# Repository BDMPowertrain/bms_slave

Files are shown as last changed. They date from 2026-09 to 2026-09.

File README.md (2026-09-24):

<p align="center" width="100%">
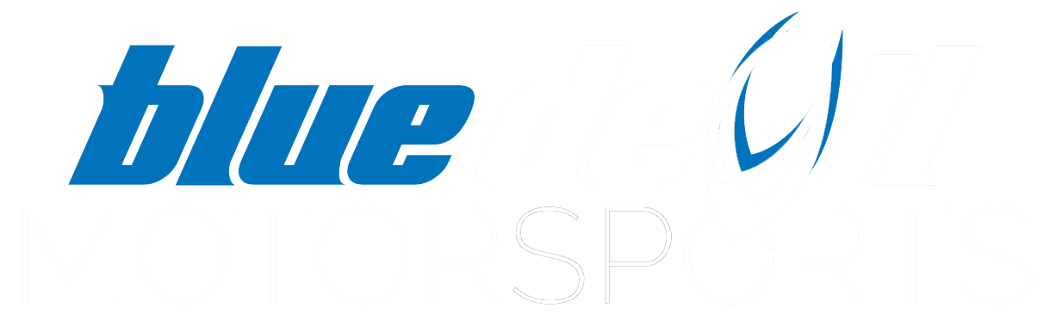
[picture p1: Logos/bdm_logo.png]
  
</p>

<h1 align="center">BOARD_NAME</h1>
<p align="center">Board Name</p>
<p align="center"><em>One-line description of what this board does.</em></p>

<p align="center" width="100%">
  <a href="https://github.com/BDMPowertrain/PLACEHOLDER/actions/workflows/ci.yaml">
    
  </a>
</p>

<p align="center" width="100%">
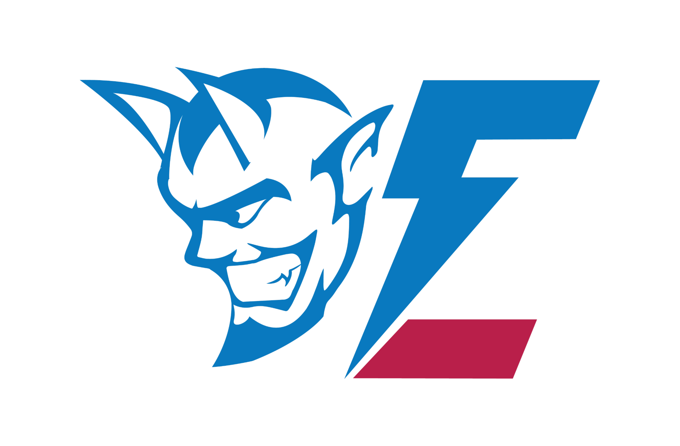
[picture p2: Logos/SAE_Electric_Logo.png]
    
</p>

***

<p align="center">
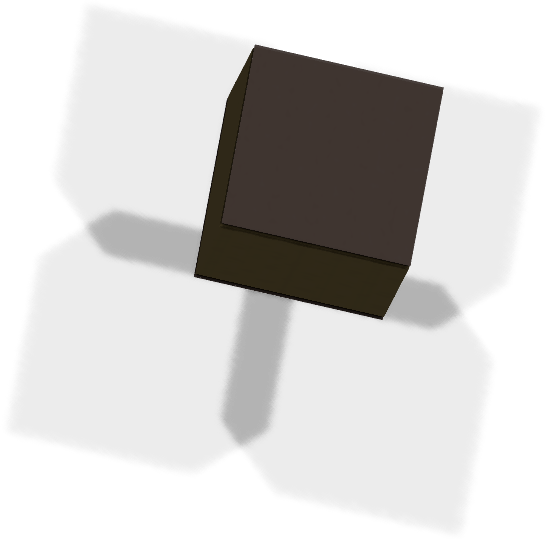
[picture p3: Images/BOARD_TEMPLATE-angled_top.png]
3D Top Angled
  
&nbsp; &nbsp; &nbsp; &nbsp;
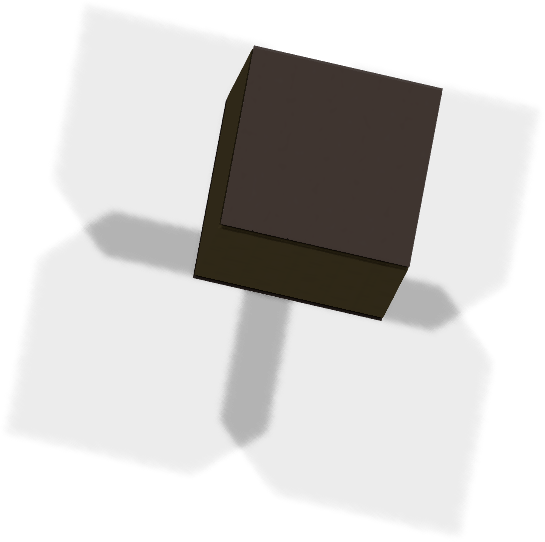
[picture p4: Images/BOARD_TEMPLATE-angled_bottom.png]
3D Bottom Angled
  
</p>

***

## SPECIFICATIONS

| Parameter | Value |
| --- | --- |
| Dimensions | 0.0 × 0.0 mm |
| Company | Blue Devil Motor Sports |
| Designer | Author |
| Revision | + (Unreleased) |

***

## WORKING ON THIS BOARD

> This file is regenerated automatically on every CI run — don't edit it by
> hand. For the full contributor guide (setup, daily commands, commit
> conventions, PR etiquette, and what to do when something goes wrong), see
> the [board_template README](https://github.com/BDMPowertrain/board_template#readme).

**Change the variant** as the board moves through Design → Procurement →
Fabrication:

    ./configure.sh --variant

**Change board metadata** (title, description, designer, company):

    ./configure.sh

RELEASED is never set by hand — push a version tag and CI produces it
automatically:

    git tag 1.0.0
    git push origin 1.0.0

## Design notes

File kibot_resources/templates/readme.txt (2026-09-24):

<p align="center" width="100%">
  
</p>

<h1 align="center">${BOARD_NAME}</h1>
<p align="center">${PROJECT_NAME}</p>
<p align="center"><em>${DESCRIPTION}</em></p>

<p align="center" width="100%">
  <a href="${GIT_URL}/actions/workflows/ci.yaml">
    CI Badge
  </a>
</p>

<p align="center" width="100%">
    
</p>

***

<p align="center">
  3D Top Angled
&nbsp; &nbsp; &nbsp; &nbsp;
  3D Bottom Angled
</p>

***

## SPECIFICATIONS

| Parameter | Value |
| --- | --- |
| Dimensions | ${bb_w_mm} × ${bb_h_mm} mm |
| Company | ${COMPANY} |
| Designer | ${DESIGNER} |
| Revision | ${REVISION} |

***

## WORKING ON THIS BOARD

> This file is regenerated automatically on every CI run — don't edit it by
> hand. For the full contributor guide (setup, daily commands, commit
> conventions, PR etiquette, and what to do when something goes wrong), see
> the [board_template README](https://github.com/BDMPowertrain/board_template#readme).

**Change the variant** as the board moves through Design → Procurement →
Fabrication:

    ./configure.sh --variant

**Change board metadata** (title, description, designer, company):

    ./configure.sh

RELEASED is never set by hand — push a version tag and CI produces it
automatically:

    git tag 1.0.0
    git push origin 1.0.0

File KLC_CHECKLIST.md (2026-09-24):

# KLC Compliance Checklist

Use this when creating or reviewing a symbol or footprint for Prism's
catalog (see the main [README](README.md#7-creating-symbols-footprints-and-adding-images),
section 7). Prism checks every submission against KLC (the KiCad Library
Convention) automatically, using `kicad-library-utils`'s checking scripts.
Go through the relevant checklist below before you submit, so nothing gets
caught by that automated check that you could have caught yourself first.

> **A note on precision.** Both official homes of `kicad-library-utils`
> ([github.com/KiCad/kicad-library-utils](https://github.com/KiCad/kicad-library-utils)
> and [gitlab.com/kicad/libraries/kicad-library-utils](https://gitlab.com/kicad/libraries/kicad-library-utils))
> are archived, with 27 branches for different KiCad versions and no single
> current canonical one. Which exact version Prism actually runs server-side
> isn't documented anywhere accessible from this repo. What follows is the
> stable, well-established core of KLC, the part that's been consistent
> across essentially every version of the tool since KiCad 6, not a claim
> that this list is the complete, exact rule set Prism enforces. If Prism's
> check flags something not listed here, that's a real finding: fix it, and
> consider asking a lead to add it to this file.

## Required symbol fields (properties)

Every symbol needs these set correctly before submission. In KiCad's Symbol
Editor, these are the Fields shown in the symbol's Properties dialog
(right-click the symbol → **Symbol Properties**, or the Fields table in the
Symbol Editor itself):

| Field | Required content | Visible on schematic? |
|---|---|---|
| `Reference` | Correct prefix for the part type, e.g. `R?`, `U?` (see the prefix table below); the `?` is what KiCad replaces with a number when the symbol is placed | Yes |
| `Value` | The MPN for ICs and complex parts, or the actual value (`10k`, `100nF`, `32.768kHz`) for simple passives | Yes |
| `Footprint` | Either left blank (only if the part is genuinely footprint-agnostic) or an exact `Library:FootprintName` reference | No, hidden |
| `Datasheet` | A direct link to the manufacturer's PDF, never a product page or distributor listing | No, hidden |
| `Description` (KiCad's internal `ki_description`) | A real, searchable one-line description of what the part actually *is* and *does*, not the MPN repeated back | No, hidden |
| `ki_keywords` | Space-separated search terms (function, package type, common synonyms) so the part is findable by more than its exact MPN | No, hidden |
| `ki_fp_filters` | Footprint name patterns, e.g. `SOIC*` or `SOT-23*`, so KiCad's footprint-assignment tool only suggests sensible candidates for this part | No, hidden |

**Why `Footprint` and `Datasheet` are hidden but `Reference` and `Value`
aren't:** the two visible fields are what a reviewer actually needs to read
off the printed schematic to identify the part. The rest is metadata for
tooling (BOM generation, footprint assignment, the library browser's
search), and clutters the schematic if shown.

## Reference designator prefixes

| Component | Prefix |
|---|---|
| Resistors | `R` |
| Capacitors | `C` |
| Inductors | `L` |
| Diodes | `D` |
| Transistors / FETs | `Q` |
| ICs (logic, analog, MCU, power, driver, interface) | `U` |
| Crystals / oscillators | `Y` |
| Connectors | `J` |
| Switches / buttons | `SW` |
| Test points | `TP` |
| Ferrite beads | `FB` |

## Symbol checklist

- [ ] Symbol name is the exact MPN, or a clear standard generic name if
      there isn't one part number that applies.
- [ ] `Reference` field prefix matches the part type (table above) and
      defaults to a bare prefix with no number, e.g. `U?` not `U1`.
- [ ] `Value` field is set correctly per the table above.
- [ ] `Footprint` field is either blank (deliberately) or points at the
      exact intended footprint in `Library:FootprintName` format.
- [ ] `Datasheet` field is a direct PDF link, not a product page.
- [ ] `Description` (`ki_description`) is filled in with a real, useful
      one-line description, not left blank or just repeating the MPN.
- [ ] `ki_keywords` has enough search terms that someone looking for this
      part by function, not just exact MPN, can actually find it.
- [ ] `ki_fp_filters` lists sensible footprint name patterns for this part.
- [ ] Every pin is numbered to exactly match the datasheet, no gaps, no
      duplicates.
- [ ] Every pin has the correct electrical type set (input, output,
      bidirectional, power input, passive, open collector, no-connect,
      etc.), not left on whatever the default was.
- [ ] Power and ground pins that must always be connected are marked
      **Power Input**, not left as generic passive or input pins.
- [ ] Unused pins are explicitly marked no-connect (small X), not just
      left floating with nothing indicating that's intentional.
- [ ] Pins sit on the 100mil (2.54mm) grid, with a consistent pin length
      across the whole symbol.
- [ ] Body outline uses a consistent, standard line width; no stray or
      overlapping graphic elements left over from editing.
- [ ] Reference and value text don't overlap the symbol body or each
      other, and are a consistent, readable size.
- [ ] No duplicate or overlapping pins at the same location.
- [ ] For multi-unit parts (e.g. a quad op-amp), each unit is split out
      and numbered correctly, with a shared unit for common power/ground
      pins if the part has one.
- [ ] Pin numbers checked against the datasheet's pin table one more time,
      right before submitting.

## Footprint checklist

- [ ] Footprint name follows a clear, consistent convention:
      `SOIC-16_3.9x9.9mm_P1.27mm`-style for standard packages,
      `MPN_Package` for custom ones. Nothing ambiguous or generic.
- [ ] Every pad is numbered to exactly match the schematic symbol's pin
      numbers; this is what makes the netlist resolve correctly.
- [ ] Pad shapes and sizes match the datasheet's mechanical/land-pattern
      drawing, not just eyeballed from a similar part.
- [ ] Pin 1 (or the equivalent orientation marker, a dot, notch, or
      bevel) is clearly marked on the silkscreen layer.
- [ ] A courtyard outline exists on `F.CrtYd` (or `B.CrtYd` for a
      bottom-side part), with a small clearance margin around the part's
      true physical body, not just the pads.
- [ ] Silkscreen graphics don't overlap any pad or exposed copper.
- [ ] The `F.Fab` (or `B.Fab`) layer shows an accurate outline of the
      part's physical body, for assembly reference.
- [ ] Reference designator text is placed somewhere it won't end up
      hidden under the part once assembled, and is a readable size.
- [ ] Value/reference text doesn't overlap pads, the courtyard boundary,
      or where neighboring components are expected to sit.
- [ ] Soldermask and paste clearance/expansion is set sensibly for the
      pad type, not left at some accidental default that bridges pads.
- [ ] For through-hole parts: drill sizes match the datasheet, with the
      correct plated vs. non-plated designation.
- [ ] A 3D model is attached and correctly aligned, scaled, and rotated
      to match the real part, if one is available.
- [ ] Footprint checked against the physical part with calipers (pad
      pitch, body size) before committing, especially for anything drawn
      by hand from a datasheet rather than downloaded from a vendor.

## Full official rule set

[klc.kicad.org](https://klc.kicad.org) and the
[kicad-library-utils](https://github.com/kicad/kicad-library-utils)
repository (the `klc-check/` scripts there are the basis for what Prism
runs against your submission). This file covers what people actually get
wrong most often, not the complete spec.

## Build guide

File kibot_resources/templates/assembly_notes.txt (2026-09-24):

ASSEMBLY NOTES (UNLESS OTHERWISE SPECIFIED)

1)	DO NOT POPULATE PARTS ARE MARKED WITH A RED CROSS.

2)	DO NOT POPULATE PARTS ARE NOT PRESENT IN THE BOM.

3)	IF CONFLICTING INFORMATION IS FOUND BETWEEN THE ASSEMBLY
	FILE AND BOM, BOM SHOULD BE USED AS THE MAIN SOURCE.

4)	CONFORMAL COATING IS NOT REQUIRED.

5)	DOT IDENTIFIES PIN #1 LOCATION AND DEVICE ORIENTATION
	WHEN VIEWED FROM THE TOP.

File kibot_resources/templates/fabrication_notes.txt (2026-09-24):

FABRICATION NOTES (UNLESS OTHERWISE SPECIFIED)

1)	FABRICATE PER IPC-6012A CLASS 2.

2)	OUTLINE DEFINED IN SEPARATE GERBER FILE WITH
	"Edge_Cuts.GBR" SUFFIX.

	DIMENSIONS OF CIRCUMSIZED RECTANGLE SHOWN ON THIS
	DRAWING FOR REFERENCE ONLY.

3)	SEE SEPARATE DRILL FILES WITH ".DRL" SUFFIX 
	FOR HOLE LOCATIONS.

	SELECTED HOLE LOCATIONS SHOWN ON THIS DRAWING 
	FOR REFERENCE ONLY.

4)	SURFACE FINISH: ${pcb_finish_cap}

5)	SOLDERMASK ON BOTH SIDES OF THE BOARD SHALL 
	BE LPI, COLOR ${solder_mask_color_text_cap}.

6)	SILK SCREEN LEGEND TO BE APPLIED PER LAYER 
	STACKUP USING ${silk_screen_color_text_cap} NON-CONDUCTIVE EPOXY INK.

7)	ALL VIAS ARE TENTED ON BOTH SIDES UNLESS 
	SOLDERMASK OPENED IN GERBER.

8)	VENDOR SHOULD FOLLOW ROHS COMPLIANT PROCESS 
	AND Pb FREE FOR MANUFACTURING

9)	PCB MATERIAL REQUIREMENTS:

	A.	FLAMMABILITY RATING MUST MEET OR EXCEED 
		UL94V-0 REQUIREMENTS.
	B.	Tg 170 C OR EQUIVALENT.
	C.	EQUIVALENT MATERIAL SHALL BE RoHS COMPLIANT, 
		HALOGEN FREE AND APPROVED BY ${COMPANY_cap}.

10)	DESIGN GEOMETRY MINIMUM FEATURE SIZES:

	BOARD SIZE				${bb_w_mm} × ${bb_h_mm} mm
	BOARD THICKNESS		${thickness_mm} mm
	TRACE WIDTH			${track_mm} mm
	TRACE TO TRACE		${clearance_mm} mm
	MIN. HOLE (PTH)			${drill_pth_real_mm} mm
	MIN. HOLE (NPTH)		${drill_npth_real_mm} mm
	ANNULAR RING			${oar_mm} mm
	COPPER TO HOLE		${c2h_mm} mm
	COPPER TO EDGE		${c2e_mm} mm
	HOLE TO HOLE			${h2h_mm} mm
#?stackup and impedance_controlled

#?stackup and impedance_controlled
11)	REFER TO IMPEDANCE TABLE FOR IMPEDANCE CONTROL REQUIREMENTS.
#?stackup and impedance_controlled

#?stackup and impedance_controlled
12)	CONFIRM SPACE WIDTHS AND SPACINGS.

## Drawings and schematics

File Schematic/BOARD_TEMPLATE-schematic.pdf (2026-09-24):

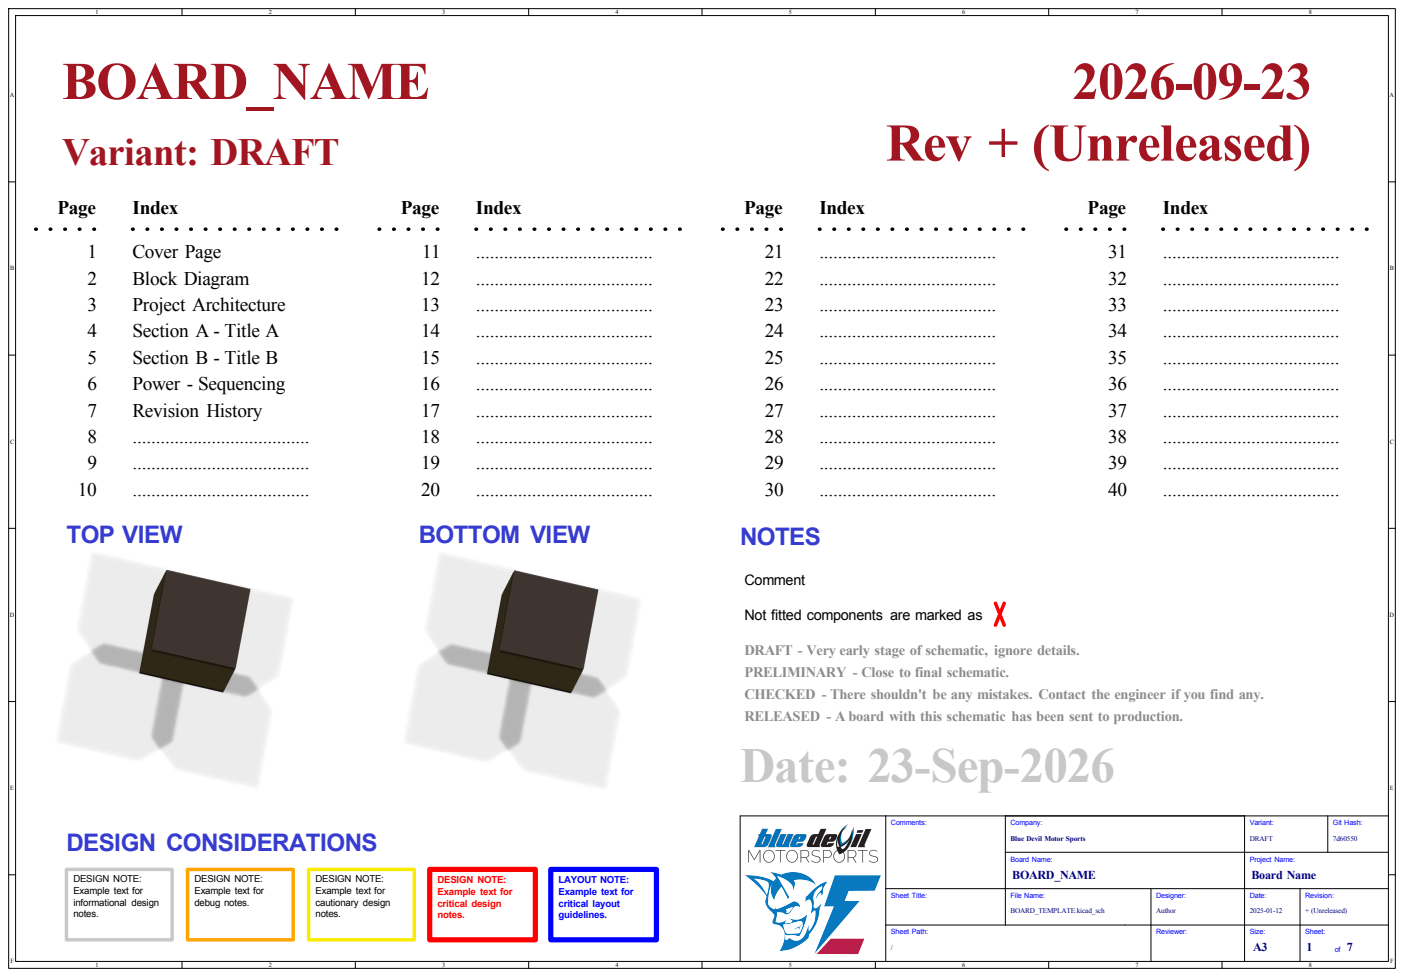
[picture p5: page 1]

...................................... Date: 23-Sep-2026
CHECKED - There shouldn't be any mistakes. Contact the engineer if you find any. ......................................

Not fitted components are marked as

DRAFT - Very early stage of schematic, ignore details.
PRELIMINARY - Close to final schematic.

RELEASED - A board with this schematic has been sent to production.

Revision: + (Unreleased) Date: Project Name: 2025-01-12 Reviewer: Designer:

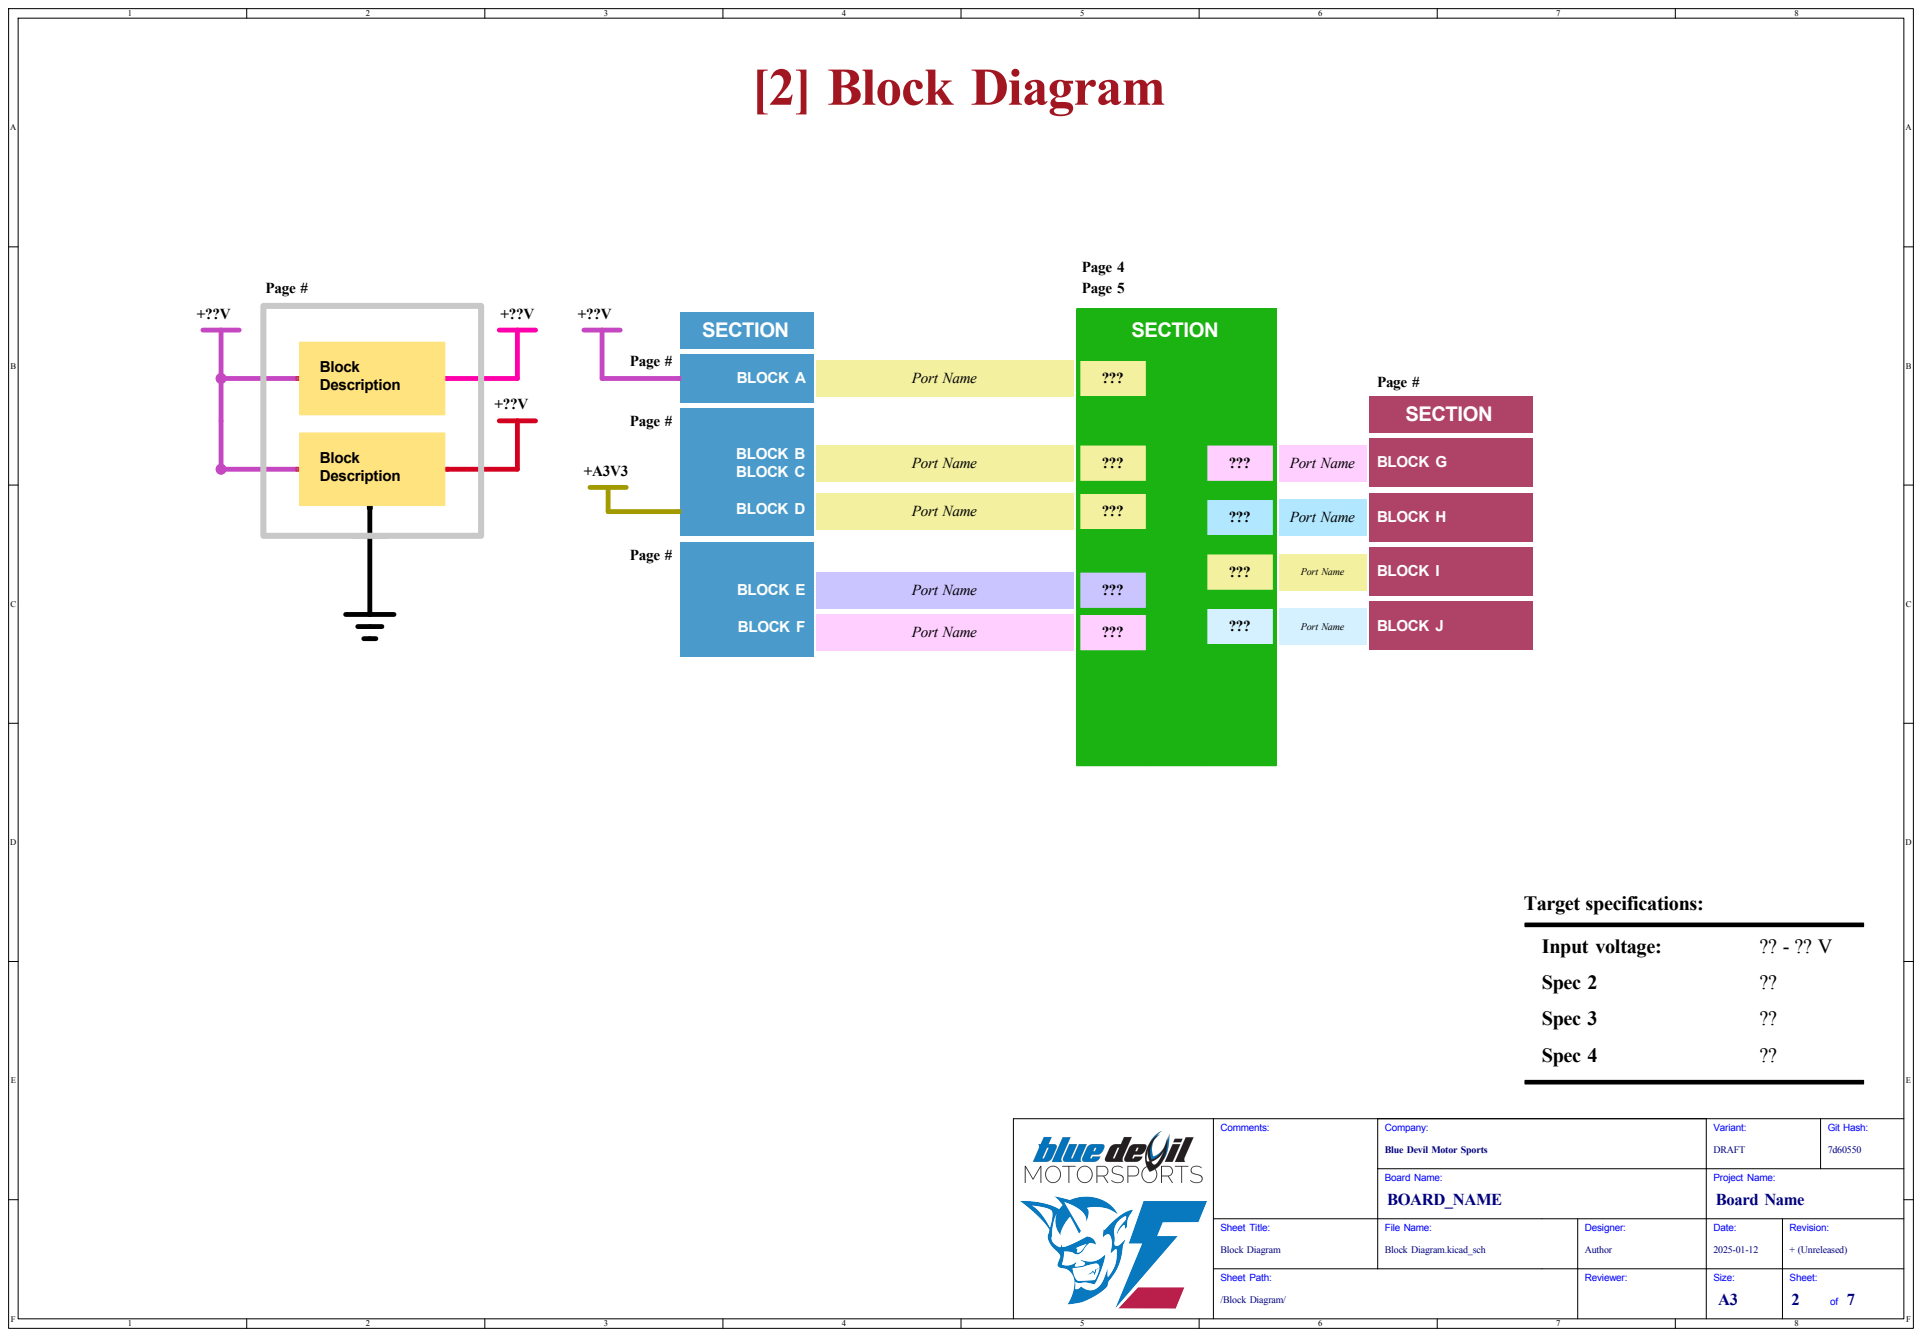
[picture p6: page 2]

Port Name

/Block Diagram/ Sheet Path: Block Diagram

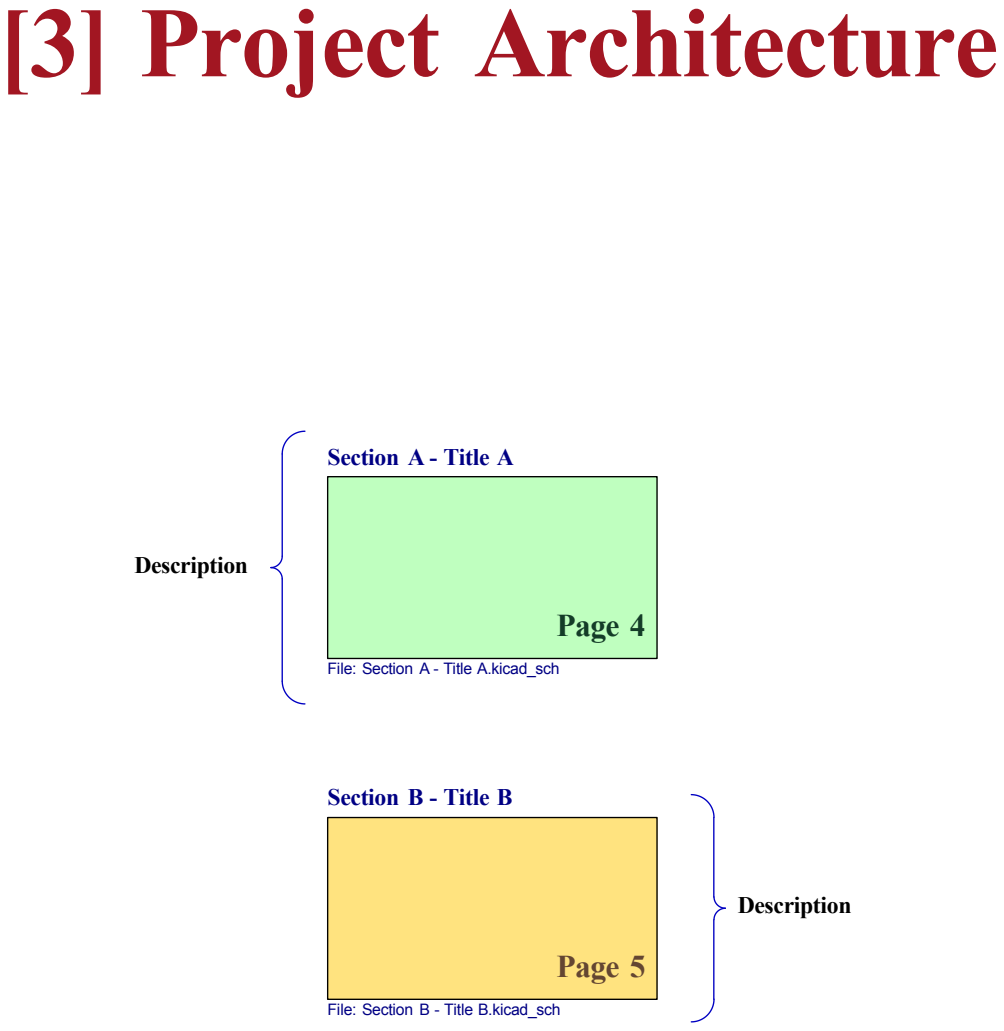
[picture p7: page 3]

Revision: + (Unreleased) Date: Project Name: 2025-01-12 Reviewer: Designer:

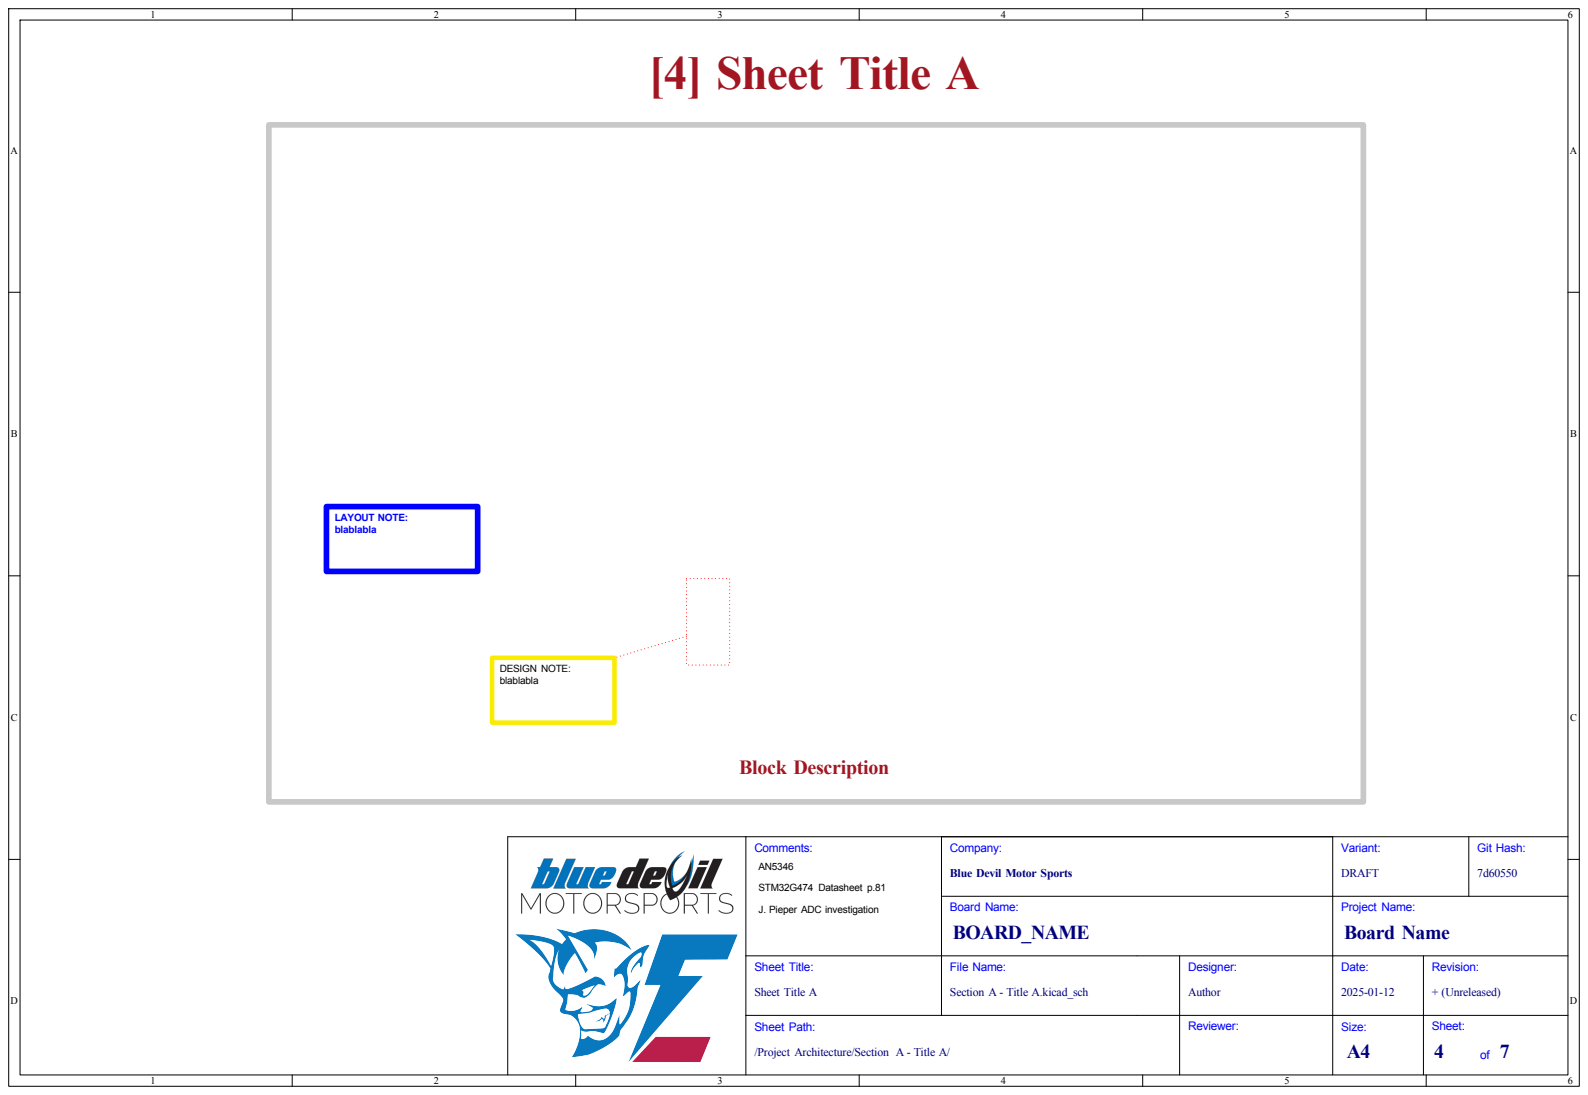
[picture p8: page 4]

J. Pieper ADC investigation (https://jpieper.com/2023/07/24/stm32g4-adc-performance-part-2/) STM32G474 Datasheet p.81 AN5346

/Project Architecture/Section A - Title A/ Sheet Path: Sheet Title A

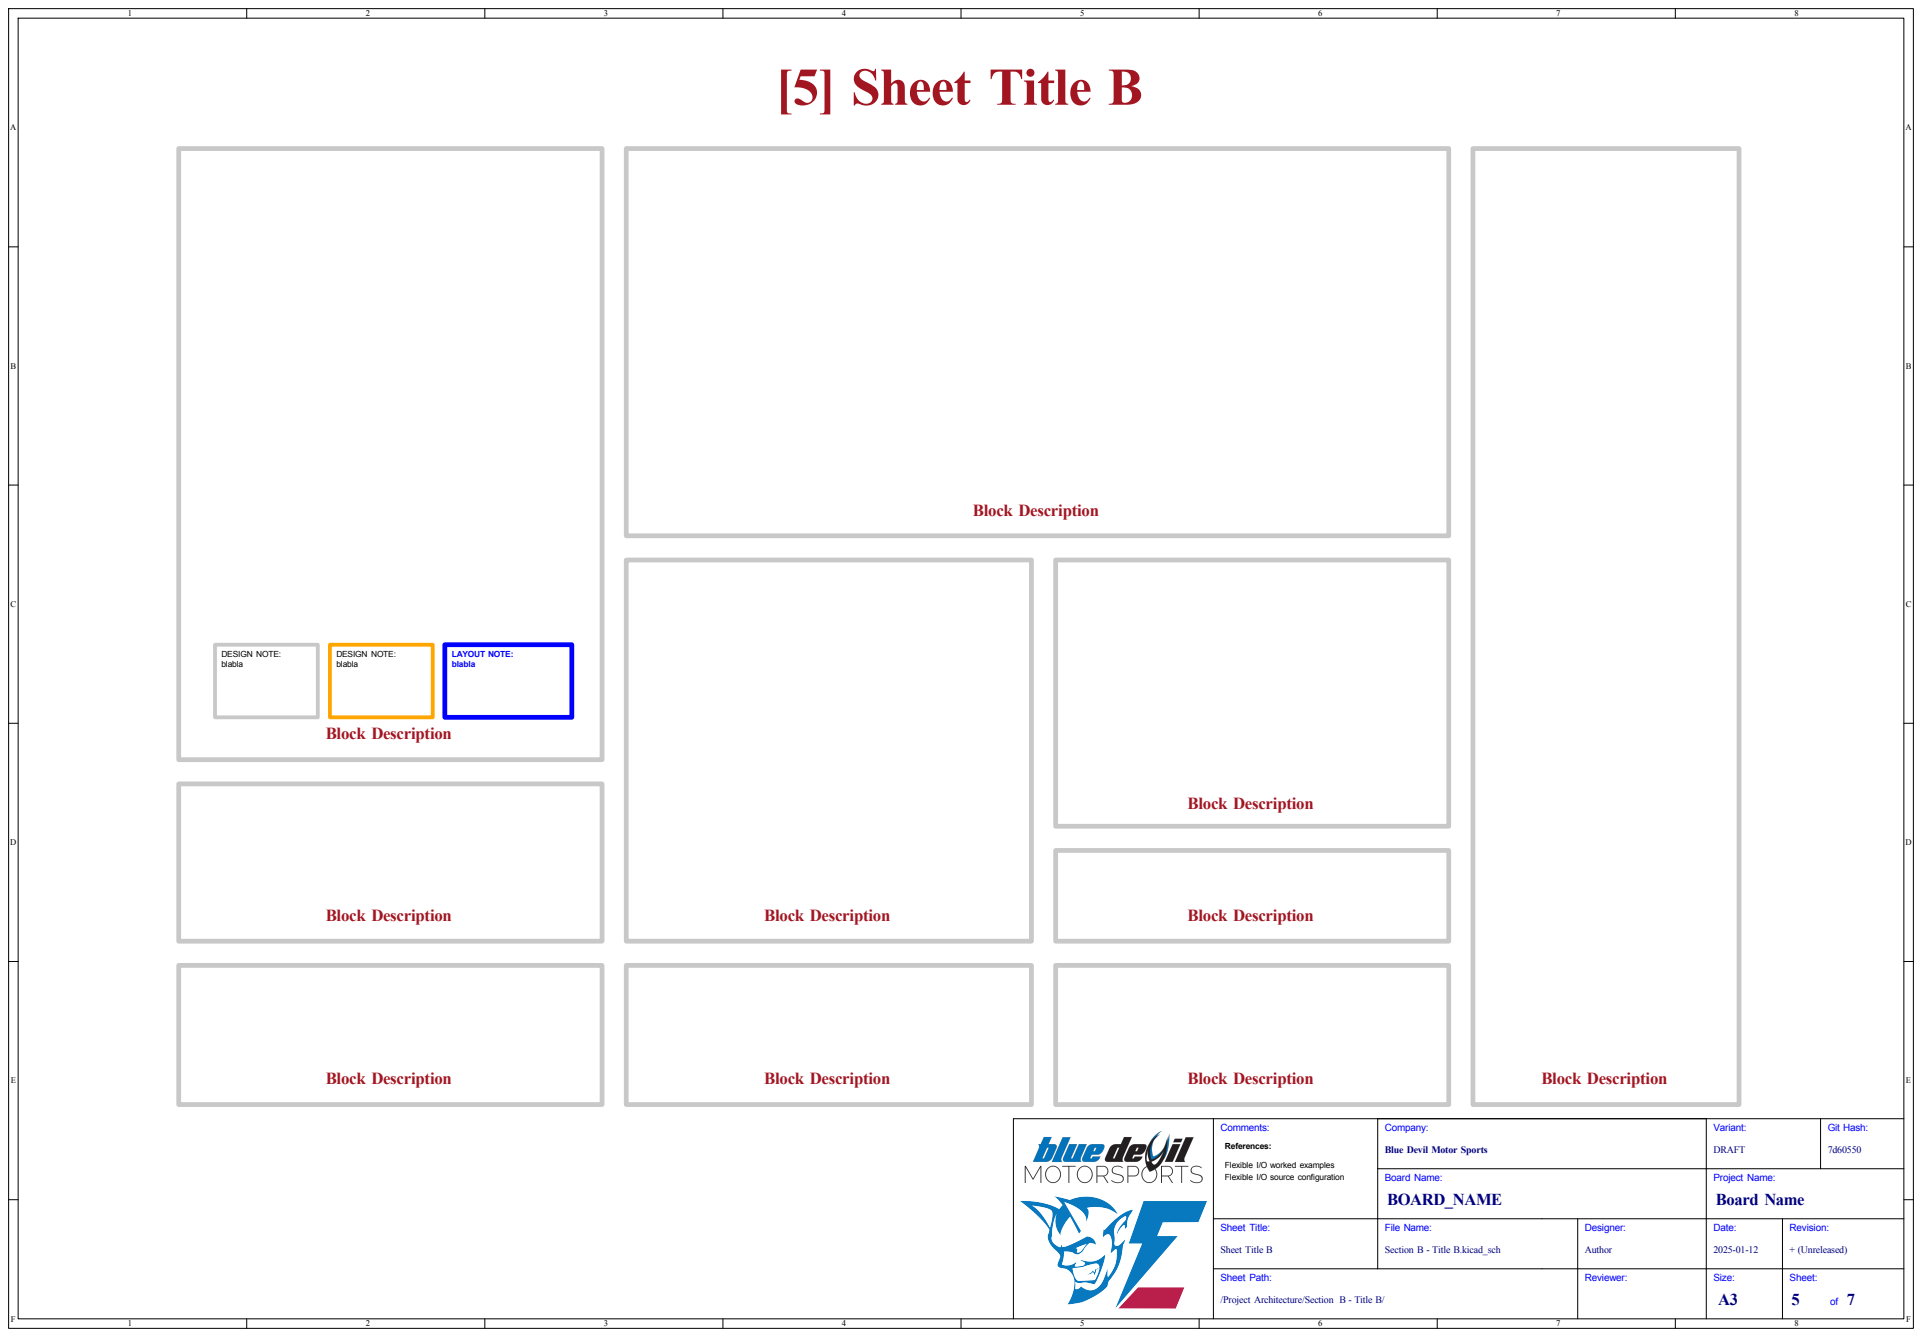
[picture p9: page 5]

Flexible I/O source configuration (https://jpieper.com/2022/06/28/flexible-i-o-source-configuration/) Flexible I/O worked examples (https://jpieper.com/2022/06/30/flexible-i-o-worked-examples/) References:

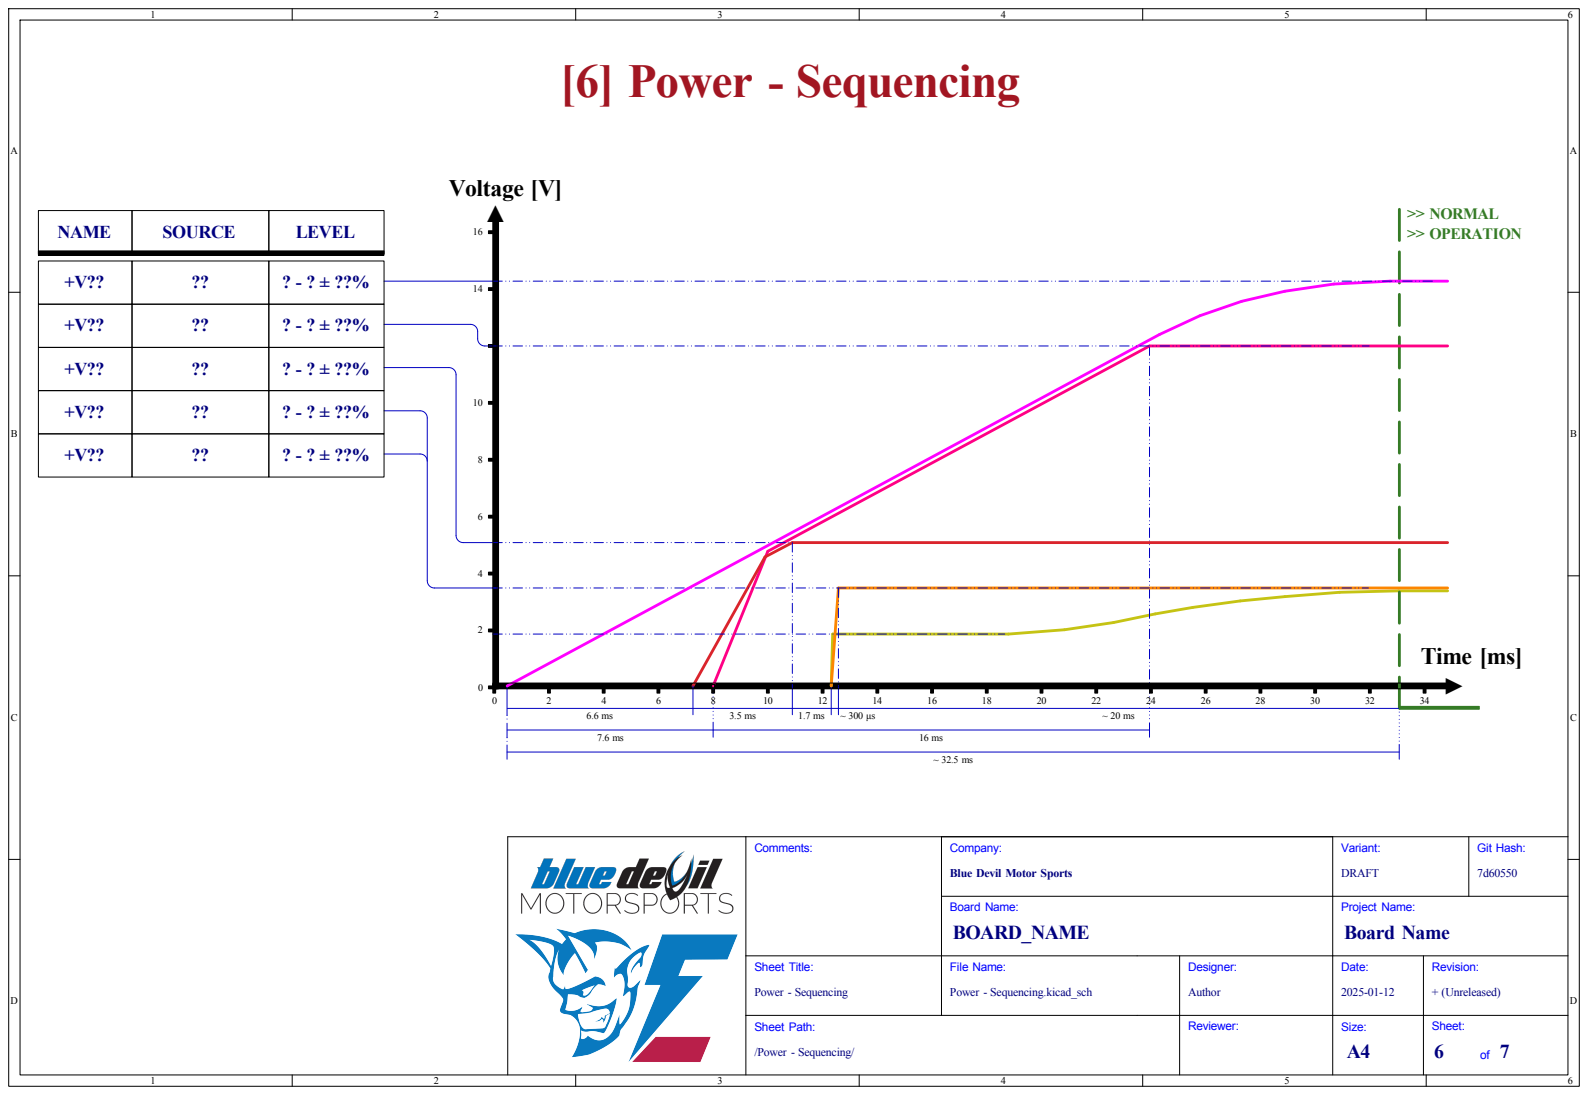
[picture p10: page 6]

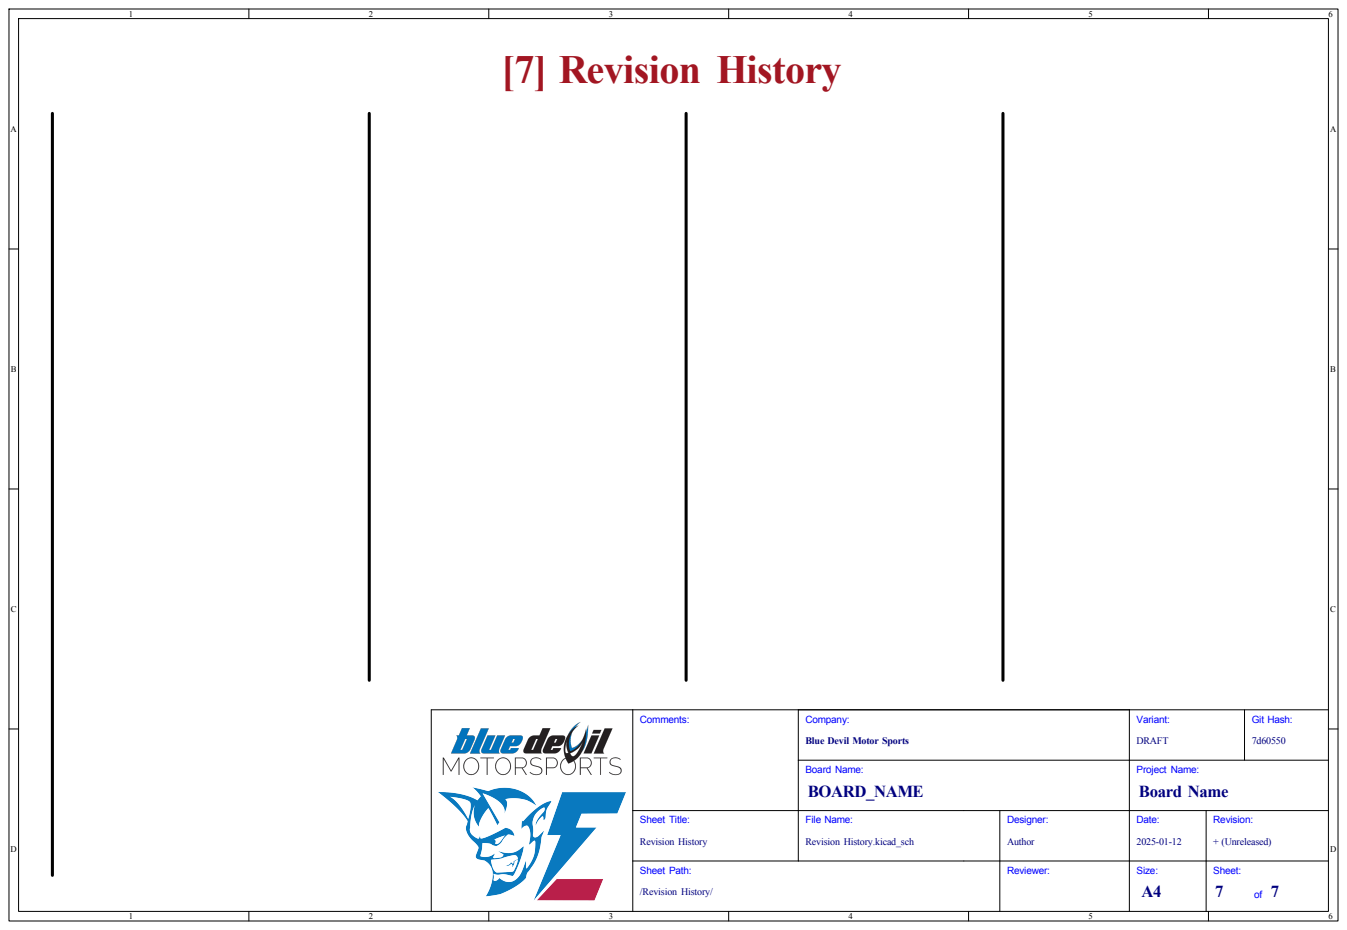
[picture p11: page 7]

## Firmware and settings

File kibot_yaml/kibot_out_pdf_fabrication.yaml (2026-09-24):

# KiBot output for generating Fabrication Document in PDF format
# https://kibot.readthedocs.io/en/latest/configuration/outputs/pcb_print.html

kibot:
  version: 1

outputs:
- name: @NAME@
  comment: '@COMMENT@'
  type: pcb_print
  category: '@DIR@'
  dir: '@DIR@'
  options:
    colored_pads: false
    colored_vias: false
    color_theme: '@COLOR_THEME@'
    output: '%f-fabrication%I%v.%x'
    format: 'PDF'
    title: '@DOC_TITLE@ Document'
    realistic_solder_mask: false
    dpi: 1200
    dnf_filter: _kibom_dnf_Config
    frame_plot_mechanism: 'internal' 
    sheet_reference_layout: '@SHEET_WKS@'
    drill:
      unify_pth_and_npth: '@PTH_NPTH@'
      group_slots_and_round_holes: @GROUP_ROUND_SLOTS@
    include_table:
      outputs:
        - name: '@NAME_TP_TOP@'
          text_alignment: 'left'
          invert_columns_order: false
          border_width: 0.4
          header_rule_width: 0.2
          horizontal_rule_width: 0
          vertical_rule_width: 0.2
          top_rule_width: 0.2
          bottom_rule_width: 0.2
          column_spacing: 2
          force_font_width: 1.27 # mm
        - name: '@NAME_TP_BOTTOM@'
          text_alignment: 'right'
          invert_columns_order: true
          border_width: 0.4
          header_rule_width: 0.2
          horizontal_rule_width: 0
          vertical_rule_width: 0.2
          top_rule_width: 0.2
          bottom_rule_width: 0.2
          column_spacing: 2
          force_font_width: 1.27 # mm
        - name: '@NAME_IMPEDANCE_TABLE@'
          text_alignment: 'left'
          invert_columns_order: false
          border_width: 0.4
          header_rule_width: 0.2
          horizontal_rule_width: 0
          vertical_rule_width: 0.2
          top_rule_width: 0.2
          bottom_rule_width: 0.2
          row_spacing: 3
          column_spacing: 2
          row_spacing: 3
        - name: '@NAME_DRILL_TABLE@'
          text_alignment: 'left'
          invert_columns_order: false
          border_width: 0.4
          header_rule_width: 0.2
          horizontal_rule_width: 0
          vertical_rule_width: 0.2
          top_rule_width: 0.2
          bottom_rule_width: 0.2
          row_spacing: 3
          column_spacing: 2
          force_font_width: 1 # mm

    pages:
      - scaling: @SCALING@
        title: '@DOC_TITLE@'
        sheet: 'Top Fabrication (Scale @SCALING@:1)'
        layer_var: 'Top Fabrication (Scale @SCALING@:1)'
        sheet_reference_color: '#000000'
        colored_holes: true
        holes_color: "#FFFFFF"
        layers:
          - layer: Edge.Cuts
            color: '#000000'
          - layer: F.Cu
            color: '#F2F2F2'
          - layer: F.Mask
            color: '#E2E2E2'
          - layer: F.Paste
            color: '#E2E2E2'
          - layer: F.Silkscreen
            color: '#DBDBDB'
          - layer: F.Fab
            plot_footprint_refs: false
            plot_footprint_values: false
            color: '#818181'
          - layer: F.Dimensions
            color: '#000000'

      - scaling: @SCALING@
        mirror: true
        mirror_pcb_text: false
        title: '@DOC_TITLE@'
        sheet: 'Bottom Fabrication (Scale @SCALING@:1)'
        layer_var: 'Bottom Fabrication (Scale @SCALING@:1)'
        sheet_reference_color: '#000000'
        colored_holes: true
        holes_color: "#FFFFFF"
        layers:
          - layer: Edge.Cuts
            color: '#000000'
          - layer: B.Cu
            color: '#F2F2F2'
          - layer: B.Mask
            color: '#E2E2E2'
          - layer: B.Paste
            color: '#E2E2E2'
          - layer: B.Silkscreen
            color: '#DBDBDB'
          - layer: B.Fab
            plot_footprint_refs: false
            plot_footprint_values: false
            color: '#818181'
          - layer: B.Dimensions
            color: '#000000'

      - scaling: @SCALING@
        title: '@DOC_TITLE@'
        sheet: 'Drill Drawing (%lp)'
        layer_var: 'Drill Drawing %lp (Scale @SCALING@:1)'
        sheet_reference_color: '#000000'
        colored_holes: true
        holes_color: "#FFFFFF"
        repeat_for_layer: '@LAYER_DRILL_MAP@'
        repeat_layers: 'drill_pairs'
        layers:
          - layer: '@LAYER_DRILL_MAP@'
            color: '#000000'
          - layer: 'Edge.Cuts'
            color: '#000000'
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

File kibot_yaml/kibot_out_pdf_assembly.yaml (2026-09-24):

# KiBot output for generating Assembly Document in PDF format
# https://kibot.readthedocs.io/en/latest/configuration/outputs/pcb_print.html

kibot:
  version: 1

outputs:
- name: @NAME@
  comment: '@COMMENT@'
  type: pcb_print
  category: '@DIR@'
  dir: '@DIR@'
  options:
    colored_vias: false
    colored_pads: false
    color_theme: '@COLOR_THEME@'
    output: '%f-assembly%I%v.%x'
    format: 'PDF'
    title: '@DOC_TITLE@ Document'
    realistic_solder_mask: false
    dpi: 1200
    dnf_filter: _kibom_dnf_Config
    # dnf_filter: '_null'
    sheet_reference_layout: '@SHEET_WKS@'
    include_table:
      outputs:
        - name: '@NAME_COMP_COUNT@'
          text_alignment: 'left'
          invert_columns_order: false
          border_width: 0.4
          header_rule_width: 0.2
          horizontal_rule_width: 0
          vertical_rule_width: 0
          top_rule_width: 0
          bottom_rule_width: 0
          row_spacing: 3
          column_spacing: 2
    pages:
      - scaling: @SCALING@
        layer_var: ''
        title: '@DOC_TITLE@'
        sheet: Top/Bottom View
        sheet_reference_color: '#000000'
        layers:
          - layer: '@LAYER_TITLE_PAGE@'
            color: '#000000'

      - scaling: @SCALING@
        layer_var: "Top Assembly (Scale @SCALING@:1)"
        title: '@DOC_TITLE@'
        sheet: Top Assembly (Scale @SCALING@:1)
        sheet_reference_color: '#000000'
        colored_holes: true
        holes_color: "#FFFFFF"
        layers:
          - layer: Edge.Cuts
            color: '#000000'
          - layer: F.Cu
            color: '#EEDAB5'
          - layer: F.Mask
            color: '#B9B9B9'
          - layer: F.Paste
            color: '#E1A98E'
          - layer: F.Silkscreen
            color: '#DB9DE1'
          - layer: F.Fab
            exclude_filter: '@FAB_EXCLUDE_FILTER@'
            color: '#744679'
          - layer: '@LAYER_ASSEMBLY_TEXT_TOP@'
            color: '#000000'
          - layer: '@LAYER_DNP_CROSS_TOP@'
            color: '#D63034'

      - scaling: @SCALING@
        layer_var: "Bottom Assembly (Scale @SCALING@:1)"
        mirror: true
        mirror_pcb_text: false
        title: '@DOC_TITLE@'
        sheet: Bottom Assembly (Scale @SCALING@:1)
        sheet_reference_color: '#000000'
        colored_holes: true
        holes_color: "#FFFFFF"
        layers:
          - layer: Edge.Cuts
            color: '#000000'
          - layer: B.Cu
            color: '#D5DBF4'
          - layer: B.Mask
            color: '#B9B9B9'
          - layer: B.Paste
            color: '#BCB9DD'
          - layer: B.Silkscreen
            color: '#DB9DE1'
          - layer: B.Fab
            exclude_filter: '@FAB_EXCLUDE_FILTER@'
            color: '#400080'
          - layer: '@LAYER_ASSEMBLY_TEXT_BOTTOM@'
            color: '#000000'
          - layer: '@LAYER_DNP_CROSS_BOTTOM@'
            color: '#D63034'

...
definitions:
  NAME: pdf_assembly
  COMMENT: Assembly document in PDF format
  DIR: Manufacturing/Assembly
  DOC_TITLE: Assembly
  COLOR_THEME: Altium_Theme
  SHEET_WKS: ${KIPRJMOD}/Templates/PCB_GIT_A4.kicad_wks
  SCALING: 1.0
  FAB_EXCLUDE_FILTER: exclude_testpoints
  LAYER_TITLE_PAGE: TitlePage
  LAYER_ASSEMBLY_TEXT_TOP: F.AssemblyText
  LAYER_ASSEMBLY_TEXT_BOTTOM: B.AssemblyText
  LAYER_DNP_CROSS_TOP: F.DNP
  LAYER_DNP_CROSS_BOTTOM: B.DNP
  NAME_COMP_COUNT: csv_comp_count

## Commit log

2026-09-24 Update Outputs
    [BOARD_TEMPLATE-bom.csv]
2026-09-24 chore: ran configure.sh
    [Project Architecture.kicad_sch, bms_slave.kicad_pcb, bms_slave.kicad_sch]
2026-09-24 SCH[Power & Balance]: Inital Schamtic for two pages.
    [CAP_UCD_6P3X7P7_NCH.step, C_0402_1005Metric.step, C_0603_1608Metric.step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]
2026-09-25 SCH:[Hiarchy, Temp, Power]:Inital schmatics of temp, balance, power mostly there need to add design notes and layout notes.
    [Project Architecture.kicad_sch, R_0402_1005Metric.step, SOD-323_1P7X1P25_ONS.step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]
2026-09-25 SCH:[Connectors]: Added connectors and lables.
    [430450200.stp, 430451600.stp, 436500200.stp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]
2026-09-28 SCH: Schmatic is close to final, need to resolve a few ERC errors nothing major. Largest change will be adding seporate wires for VBAT and RefGround / Tap 0. connector position and types may change a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
    [430450200.stp, 430451600.stp, 436500200.stp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]
2026-10-03 SCH[Cleaning]:Updated Connectors not sure still, added sprate bat and ground connections, updated commincation conncetors. PCB[Layout]:Inital layout of compents need to fit on board size once tap con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
    [430450212.stp, 430451200.stp, 430451612.stp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]
2026-10-04 PCB[Part Layout]: Working on routing and part arragement more, thinking im going to go with the two row connector for bat connections, might have to put parts on both sides for cleaner routing for ba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
    [436501200.stp, bms_slave.kicad_pcb, connectors.kicad_sch]
2026-10-05 PCB[Rules]: Updated rules, via & trace size, clearnace, and board stackup.
    [bms_slave.kicad_pcb]
2026-10-06 PCB[Dasiy, Sens, Bal]:Added clearnece rules for pad to Daisy, 3W for Daisy, Via shield, started routing for bal and sens.
    [bms_slave.kicad_pcb]
2026-10-06 SCH[Connector]: Updated tap, and temp connectors to two row variants for space, combined grounds to one pin for the temp assuming the battery interface board combines those grounds.
    [430451024.STEP, 430451200.stp, bms_slave.kicad_pcb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]
2026-10-06 PCB[Routing, Power, Connectors, Board Size]:Adjusted routing for temp and sens, placed bjt on board, adjusted connector placement and connections, changed board sized to match connectors better.
    [430451024.stp, bms_slave.kicad_pcb, connectors.kicad_sch]
2026-10-07 PCB[DRC, Grouding]: Need to seprate top ground planes, and possibliy bring caps to top side, started adressing drc errors. To fix: Via sizing on bms chip, ground planes and senstive grounds, trace ma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
    [mechanical.kicad_sch]
2026-10-14 PCB[Layout]: Inital layout changes for board to board connector change. >> SCH[Connector]: Changed connectors for right angle micro fit 3.0 for iso spi chanels, and changed to board to board samtech 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
2026-10-14 PCB[Layout]: Messed more withlayout, might try to intgrate into interface board afterall...
2026-10-15 PCB[Routing, Silk]: Everything but led routed, need to do via stiching, and finish adding silk screen.
2026-10-16 PCB[Holes]: Updated hole positioning.
2026-10-16 PCB[Silkscreen, DRC]: Though all drc erros minus one, not an issue just need to clear. Added silk logos
2026-10-17 PCB[Mounting]: Messing with mounting holes for board to board connection. SCH[Naming]: Small naming changes, T_P -> TMP
2026-10-18 PCB[Grounding, Heat]: Added some more pours for heat considerations for bjt, stiched more vias for heat consideration on balanace resistors. SCH[Notes, Block Diagram]: Working on spelling and notes u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
2026-10-18 PCB[Test Points, Mechanical, Silk]: Finalized Mounting Points, Added Testpoints with adjecent silkscreen labels. SCH[Test Points, Notes]: Added/Updated notes for all pages, cleaned up errors spelling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
2026-10-18 Fix YAML quoting of free-text fields; single cross-platform configure menu
    KiBot substitutes @VAR@ definitions as raw text before parsing YAML, so the
    unquoted DESCRIPTION/PROJECT_NAME/COMPANY/DESIGNER passthroughs broke every
    run once a value contained ": ". Quote them, and rewrite configure.py so it
    validates input, double-quotes what it writes, and refuses to save a config
    KiBot can't parse (also available as --check / --check --fix).
    configure.py is now a menu (stage, board info, show settings, check) that
    runs directly on Windows and Linux, replacing configure.sh/configure.bat.
2026-10-18 Full-detail STEP export; top/bottom renders in README and schematic
    - STEP: switch from KiBot's `step` output to `export_3d` so the model
    includes tracks, pads, zones, inner copper, silkscreen and soldermask
    (fused shapes, vias cut in body/filled, drill origin, 0.01 mm min
    distance), matching the kicad-cli flags we use by hand.
    - README and schematic cover page now use the straight top/bottom renders
    instead of the angled ones.
    - Angled renders are still generated, now zoomed out (-4) so the rotated
    board no longer clips the frame; auto_crop trims the margin.
2026-10-18 STEP export: turn off fuse_shapes so CI doesn't fail
    On bms_slave, kicad-cli reports "Problems encountered while fusing shapes"
    (OpenCASCADE BOPAlgo warnings) and exits 2, which KiBot treats as a failed
    output even though the STEP file is written. Reproduced locally with KiCad
    10.0.5; the same export without --fuse-shapes exits 0, keeps all copper /
    silkscreen / soldermask, and runs in ~30 s instead of ~67 s.
2026-10-18 Render angled 3D views in perspective so they don't clip
    KiBot passes render_3d's `zoom` to kicad-cli as the camera Z in `--pan`,
    which has no effect with an orthographic camera, so 3D_VIEWER_ZOOM: -4
    didn't shrink the angled views and the board stayed clipped. Make
    `orthographic` a per-render definition (default true) and set it to false
    for the two angled renders. Verified locally with kicad-cli 10.0.5 on
    bms_slave: perspective at -4 fits with margin; orthographic at -4 clips.
2026-10-20 DRAFT README pass: generate all four 3D renders
    readme_group (DRAFT-only README pass) generated just the two angled
    renders, but the README now shows the top/bottom ones, so DRAFT boards got
    broken README images. Run the whole 3d_render group instead.
2026-10-21 PCB&SCH[Fid]: Added 3 fiductals on the back for fab.
2026-10-29 PCB[Trace Size, Testpad, Daisy]: Changed Bat Trace size FAT, Made test pads larger, small trace movement to clean up, daisy trace change. SCH[Notes]: Small notes changes.
2026-10-29 README: drop stale "Working on this board" section
2026-11-02 configure.py: rewrite absolute RemoteLibrary paths to ${KIPRJMOD}
    Update configure.py from the template and run it, fixing this board's
    machine-specific RemoteLibrary paths in fp-lib-table / sym-lib-table.
2026-11-02 Catch merge conflicts and invalid JSON in KiCad project files
    configure.py --check and a new first CI step now fail on git conflict
    markers in the .kicad_pro/.kicad_sch/.kicad_pcb and library tables, and
    on a .kicad_pro that isn't valid JSON, naming the file and line. CI's
    own GIT_HASH_* commits make .kicad_pro pull conflicts common; one
    committed as-is broke battery_interface_board and KiCad then reset its
    project settings to defaults.
2026-11-03 PCB[Clearnce]: Small clearence fixes, rules clearence fix.
2026-11-03 PCB[Mounting]: Centered main board to board connector, was not aligned in cad module intgration.
